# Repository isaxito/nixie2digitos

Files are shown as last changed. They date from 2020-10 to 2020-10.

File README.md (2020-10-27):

 Esquematicos y codigo pedorro actual del reloj nixie de 2 digitos que diseñé con 2 tubos IN-12.
 El codigo por ahora solo es para que funcione pero está abierta la posibilidad de meterle varias cosas, usé el core del attiny85 este: https://github.com/SpenceKonde/ATTinyCore
### Fotolas
No soy bueno sacando fotos, no puedo hacer que se los tubos se vean tan hermosos como se ven en persona
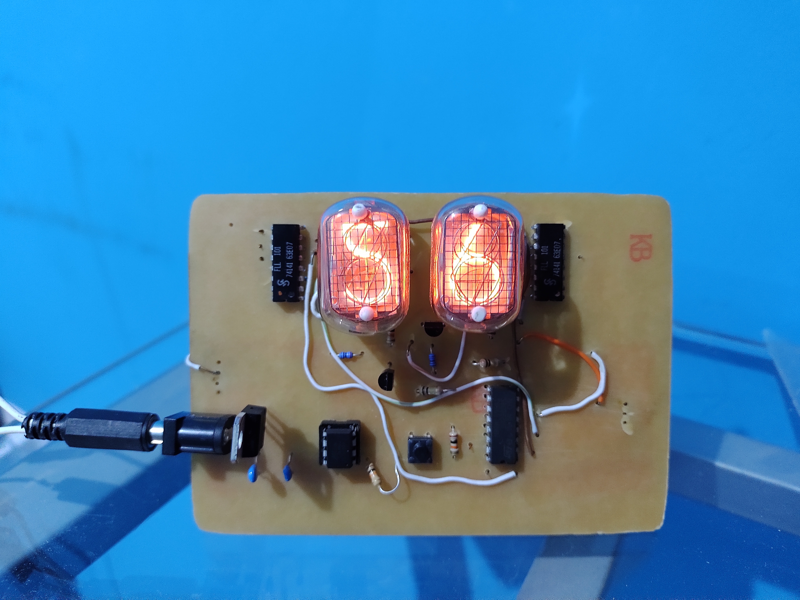
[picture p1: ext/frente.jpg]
Frente Foto del frente

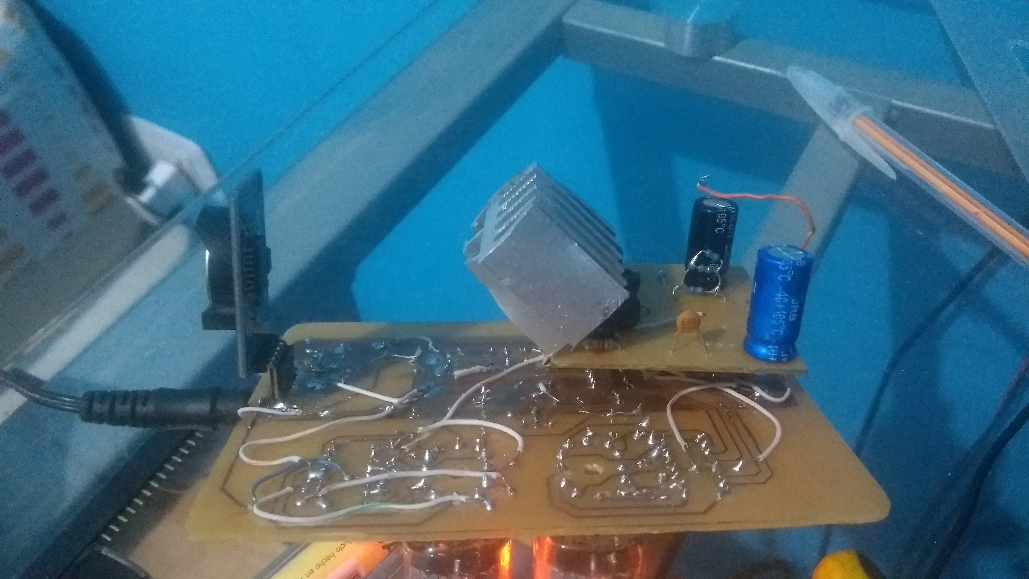
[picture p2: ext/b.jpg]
Atras

Fuente Foto de la fuente
Atras

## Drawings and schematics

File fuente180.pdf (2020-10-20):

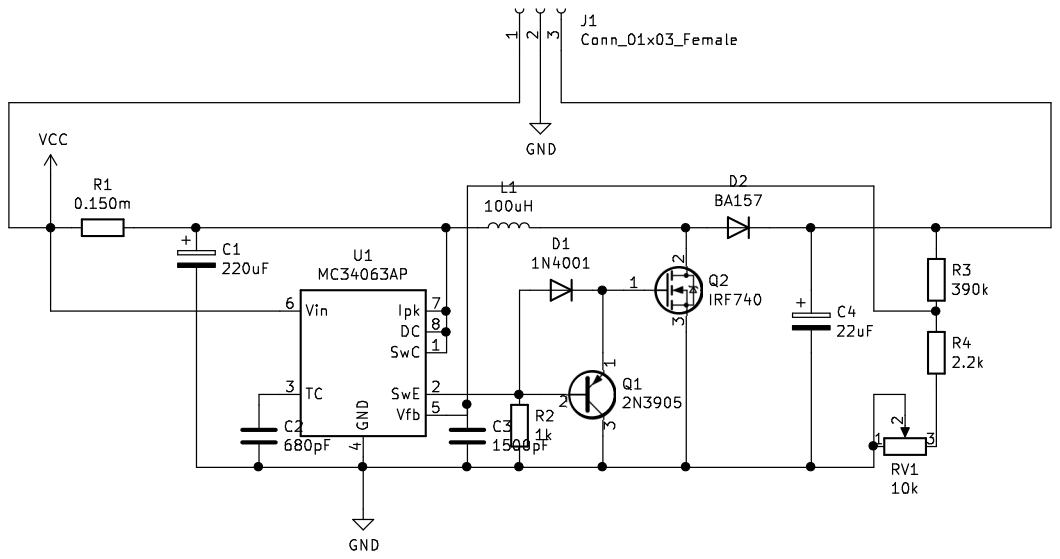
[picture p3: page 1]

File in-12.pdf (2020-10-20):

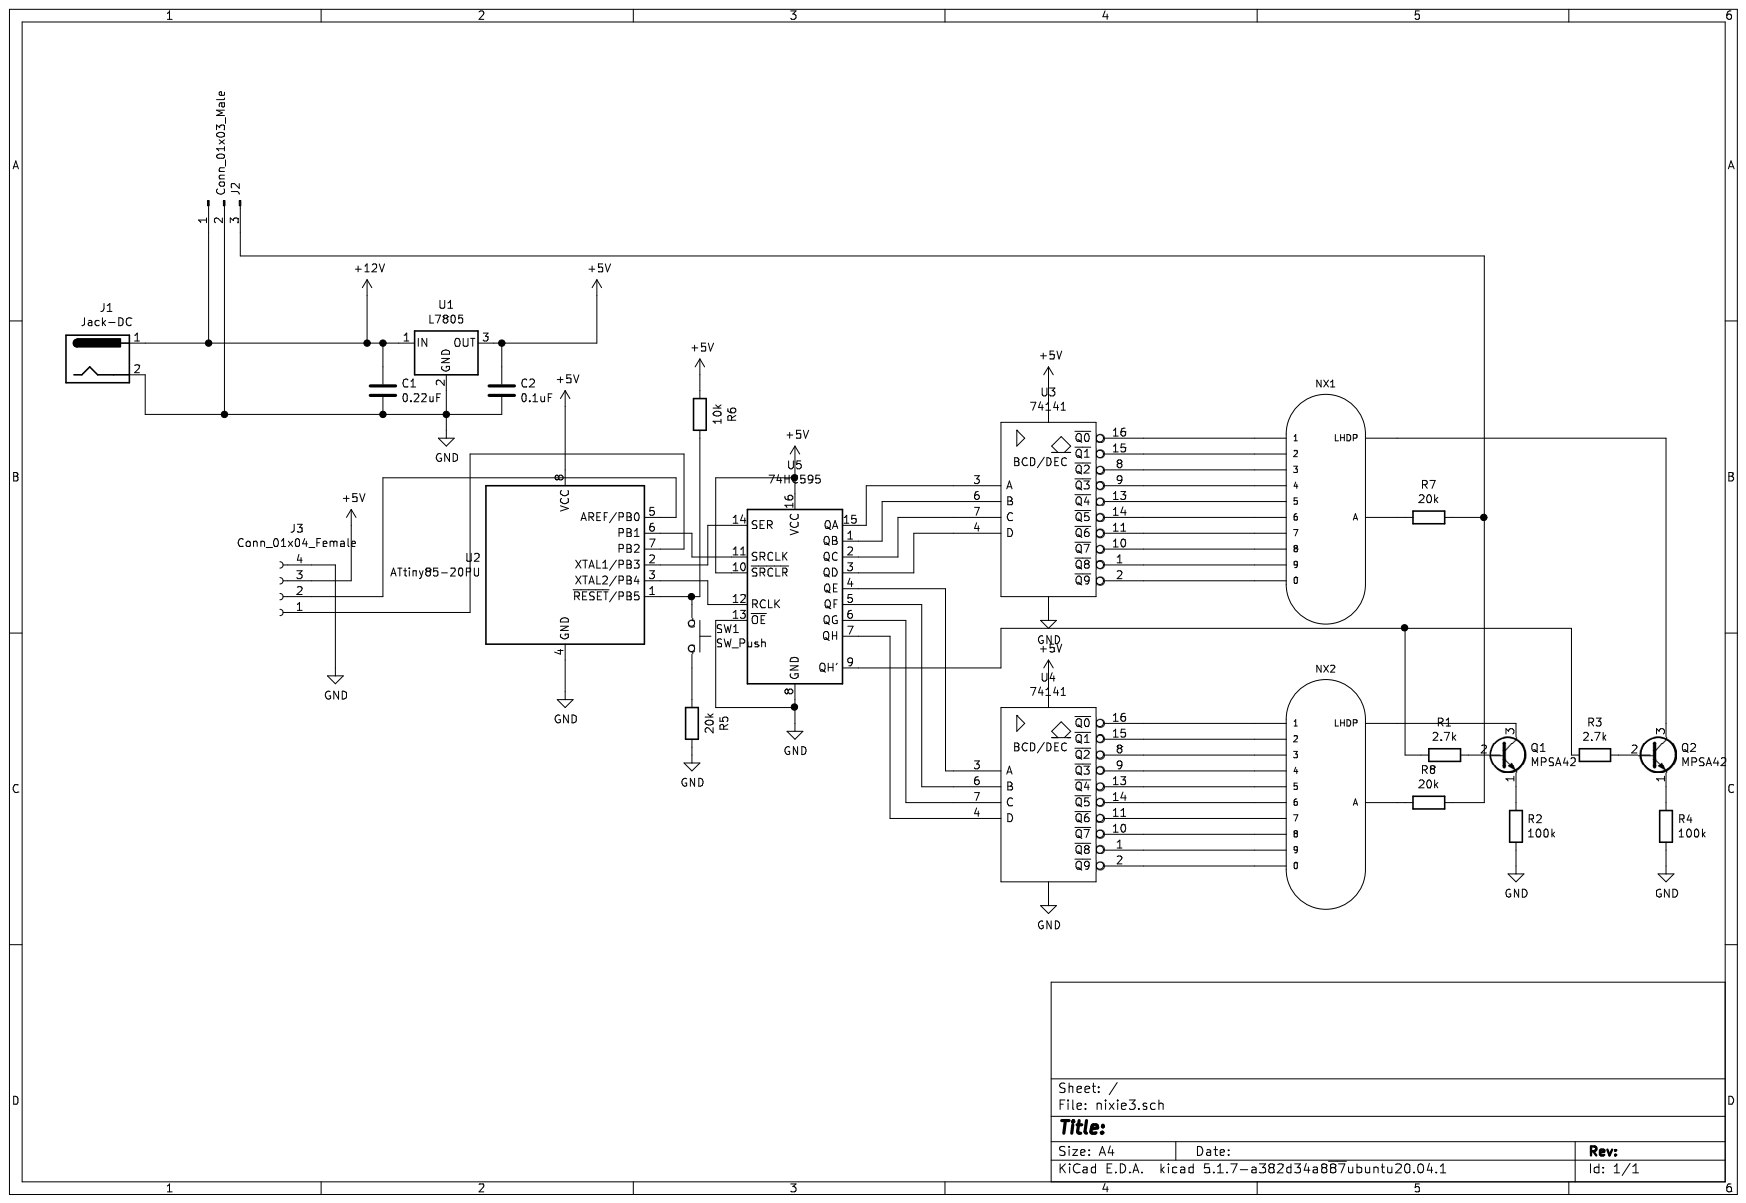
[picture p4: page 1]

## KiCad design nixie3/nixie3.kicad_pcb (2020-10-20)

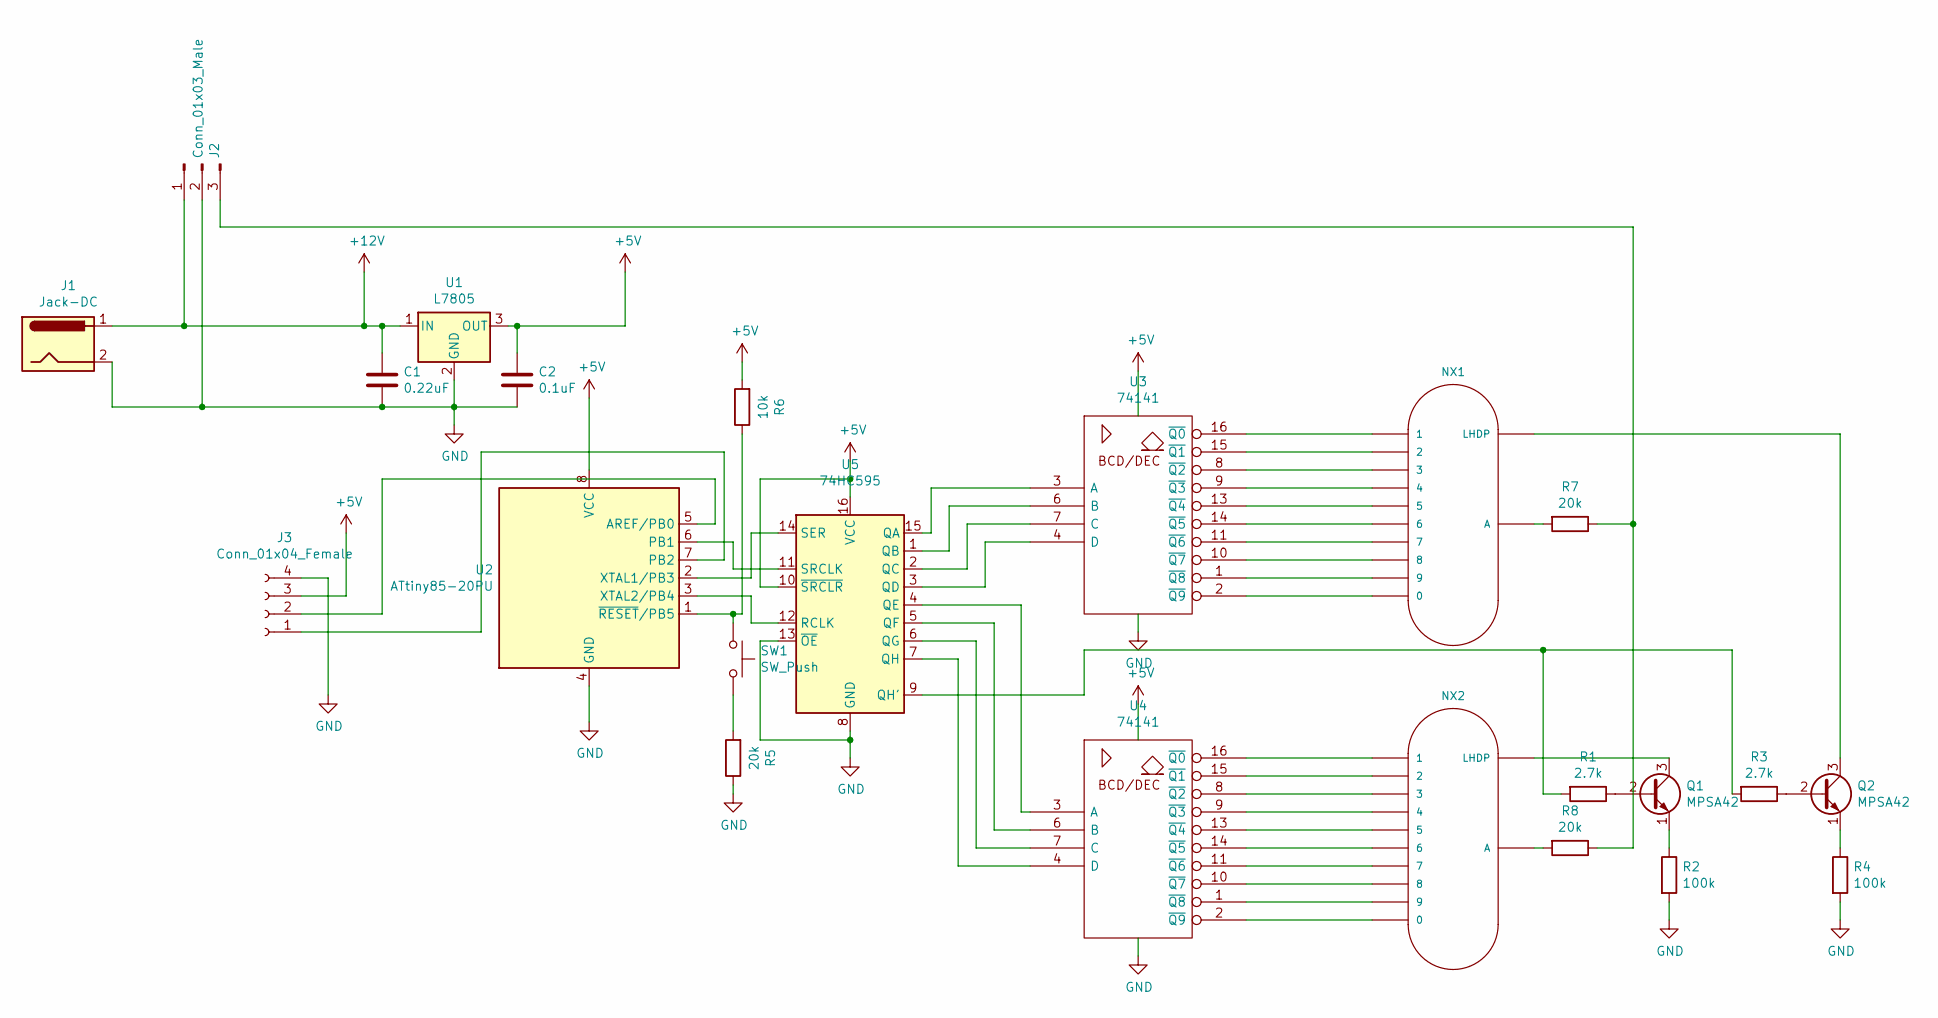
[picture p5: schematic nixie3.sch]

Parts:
C1: 0.22uF; C_Disc_D5.1mm_W3.2mm_P5.00mm
C2: 0.1uF; C_Disc_D5.1mm_W3.2mm_P5.00mm
J1: Jack-DC; BarrelJack_CUI_PJ-102AH_Horizontal
J2: Conn_01x03_Male; PinHeader_1x03_P2.54mm_Vertical
J3: Conn_01x04_Female; PinHeader_1x04_P2.54mm_Vertical
NX1, NX2: IN-12BORIGINAL; nixies-us-IN-12
Q1, Q2: MPSA42; TO-92_Inline_Wide
R1, R3: 2.7k; R_Axial_DIN0207_L6.3mm_D2.5mm_P7.62mm_Horizontal
R2, R4: 100k; R_Axial_DIN0207_L6.3mm_D2.5mm_P7.62mm_Horizontal
R5, R7, R8: 20k; R_Axial_DIN0207_L6.3mm_D2.5mm_P7.62mm_Horizontal
R6: 10k; R_Axial_DIN0207_L6.3mm_D2.5mm_P7.62mm_Horizontal
SW1: SW_Push; SW_PUSH_6mm_H5mm
U1: L7805; TO-220-3_Vertical
U2: ATtiny85-20PU; DIP-8_W7.62mm
U3, U4: 74141; DIP-16_W7.62mm
U5: 74HC595; DIP-16_W7.62mm

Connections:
+5V: C2.1, J3.3, R6.2, U1.3 (OUT), U2.8 (VCC), U3.5 (VCC), U4.5 (VCC), U5.10 (~SRCLR), U5.16 (VCC)
+12V: C1.1, J1.1, J2.1, U1.1 (IN)
GND: C1.2, C2.2, J1.2, J2.2, J3.4, R2.2, R4.2, R5.1, U1.2 (GND), U2.4 (GND), U3.12 (GND), U4.12 (GND), U5.8 (GND), U5.13 (~OE)
unnamed: J2.3, R7.1, R8.1
unnamed: J3.1, U2.7 (PB2)
unnamed: J3.2, U2.5 (AREF/PB0)
unnamed: NX1.0, U3.2 (~Q9)
unnamed: NX1.1, U3.16 (~Q0)
unnamed: NX1.2, U3.15 (~Q1)
unnamed: NX1.3, U3.8 (~Q2)
unnamed: NX1.4, U3.9 (~Q3)
unnamed: NX1.5, U3.13 (~Q4)
unnamed: NX1.6, U3.14 (~Q5)
unnamed: NX1.7, U3.11 (~Q6)
unnamed: NX1.8, U3.10 (~Q7)
unnamed: NX1.9, U3.1 (~Q8)
unnamed: NX1.A, R7.2
unnamed: NX1.LHDP, Q2.3 (C)
unnamed: NX2.0, U4.2 (~Q9)
unnamed: NX2.1, U4.16 (~Q0)
unnamed: NX2.2, U4.15 (~Q1)
unnamed: NX2.3, U4.8 (~Q2)
unnamed: NX2.4, U4.9 (~Q3)
unnamed: NX2.5, U4.13 (~Q4)
unnamed: NX2.6, U4.14 (~Q5)
unnamed: NX2.7, U4.11 (~Q6)
unnamed: NX2.8, U4.10 (~Q7)
unnamed: NX2.9, U4.1 (~Q8)
unnamed: NX2.A, R8.2
unnamed: NX2.LHDP, Q1.3 (C)
unnamed: Q1.1 (E), R2.1
unnamed: Q1.2 (B), R1.1
unnamed: Q2.1 (E), R4.1
unnamed: Q2.2 (B), R3.1
unnamed: R1.2, R3.2, U5.9 (QH')
unnamed: R5.2, SW1.2
unnamed: R6.1, SW1.1, U2.1 (~RESET~/PB5)
unnamed: U2.2 (XTAL1/PB3), U5.14 (SER)
unnamed: U2.3 (XTAL2/PB4), U5.12 (RCLK)
unnamed: U2.6 (PB1), U5.11 (SRCLK)
unnamed: U3.3 (A), U5.15 (QA)
unnamed: U3.4 (D), U5.3 (QD)
unnamed: U3.6 (B), U5.1 (QB)
unnamed: U3.7 (C), U5.2 (QC)
unnamed: U4.3 (A), U5.4 (QE)
unnamed: U4.4 (D), U5.7 (QH)
unnamed: U4.6 (B), U5.5 (QF)
unnamed: U4.7 (C), U5.6 (QG)

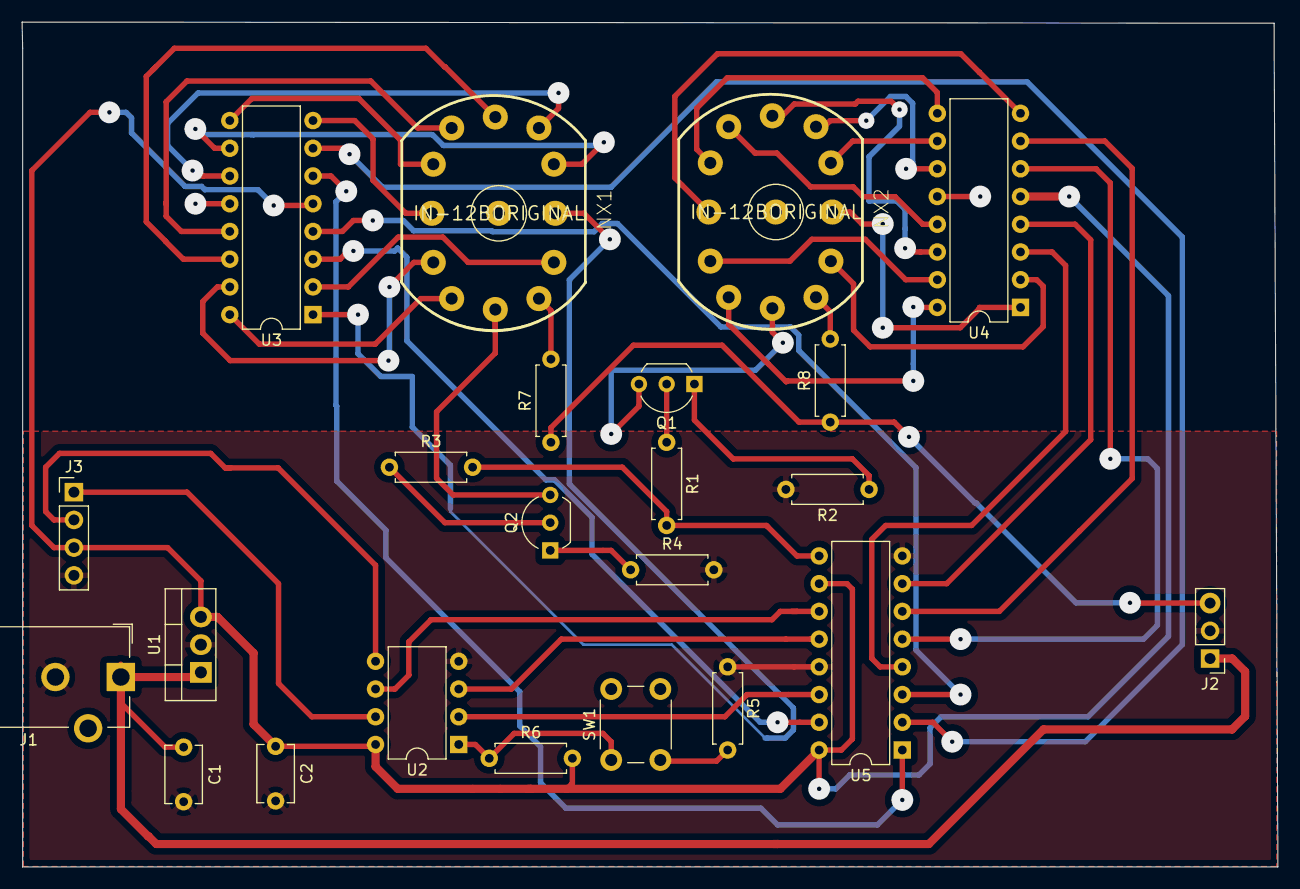
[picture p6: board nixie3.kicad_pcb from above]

Board: 2 copper layers, 115.0 x 77.4 mm, 23 parts (0 on the bottom side), 48 nets.

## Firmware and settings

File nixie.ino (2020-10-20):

#include <Wire.h>
#include "RTClib.h"

#define punto 255

// SDA 5
// SCL 7

#define pinDato 3      // Pin conectado a DS pin 14 de 74HC595
#define pinClock 1  // Pin conectado a SHCP pin 11 de 74HC595
#define pinRegistro 4  // Pin conectado a STCP pin 12 de 74HC595
RTC_DS3231 rtc;
int horas, minutos;

int cambiar (int num);
void mostrarNum(int num);
int  decimalToBCD (int decimal);

void setup() {
  Wire.begin();
  pinMode(pinRegistro, OUTPUT);
  pinMode(pinClock, OUTPUT);
  pinMode(pinDato, OUTPUT);
  digitalWrite(pinRegistro, LOW);
}

void loop() {
  DateTime now = rtc.now();

  // Muestra la hora
  horas = now.hour();
  mostrarNum(cambiar(horas));
  delay(1000);

  // Muestra los puntos
  shiftOut(pinDato, pinClock, MSBFIRST, punto);
  digitalWrite(pinRegistro,HIGH);
  digitalWrite(pinRegistro,LOW);
  shiftOut(pinDato, pinClock, MSBFIRST, punto);
  digitalWrite(pinRegistro,HIGH);
  digitalWrite(pinRegistro,LOW);
  delay(700);

  // Apaga el punto y muestra los minutos
  minutos = now.minute();
  mostrarNum(cambiar(minutos));
  delay(1000);

  // BLANCO
  shiftOut(pinDato, pinClock, MSBFIRST, B10101010);
  digitalWrite(pinRegistro, HIGH);
  digitalWrite(pinRegistro, LOW);
  delay(500);
  

}

int cambiar(int num)
{
  int d1, d2, nfinal;
  d1 = num % 10;
  d2 = (num / 10) % 10;
  if (d1 == 0)
    d1 = 9;
  else
    d1--;
  if (d2 == 0)
    d2 = 9;
  else
    d2--;
  nfinal = d2 + d1 * 10;
  return nfinal;
}
void mostrarNum(int num)
{
  shiftOut(pinDato, pinClock, MSBFIRST, decimalToBCD(num));
  digitalWrite(pinRegistro, HIGH);
  digitalWrite(pinRegistro, LOW);
}

int  decimalToBCD (int decimal)
{
  return (((decimal / 10) << 4) | (decimal % 10));
}
